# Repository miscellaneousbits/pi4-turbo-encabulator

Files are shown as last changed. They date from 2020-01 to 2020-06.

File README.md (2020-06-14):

# Raspberry Pi4 Turbo Encabulator
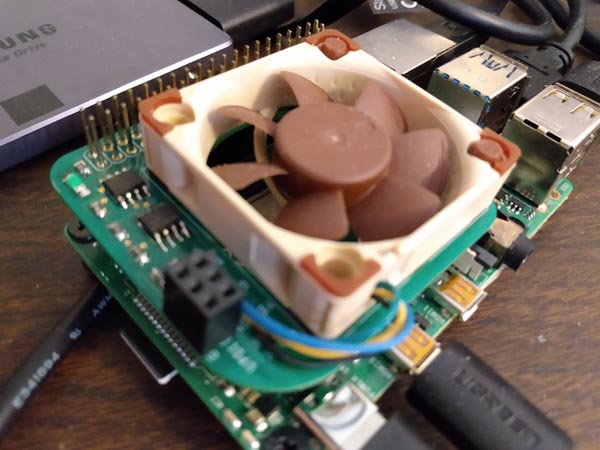
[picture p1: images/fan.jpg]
Image of Encabulator


I wanted fan speed control of a 4 wire Noctua fan with PWM, but I didn't want to dedicate one of the Pi's PWM pin for that purpose. I decided to use I2C, a shareable bus, for fan control. Ended up using a small 8 pin Atmel micro controller to support I2C and PWM to the fan. The second 8 pin package is a dual FET to handle 3.3V to 5V conversions.

## Building the Turbo Encabulator hat

You'll find everything you need in the hardware folder. Use the bill of materials file to place your parts order. Also place your board order with the fabricator. Gerber files and Exelon drill files are the standard inputs for the board fab. The design uses surface mount parts, and hand soldering the fine pitch components can be challenging.

## Programming the Atmel ATtiny212

The ATtiny212 packs an amazing amount of capabilities for an 8 bit processor in an 8 pin package (and we use all 8 pins!). I use it here to implement an I2C slave interface and a PWM generator for the fan. The microcontroller has dedicated I2C and PWM hadware blocks, so no bit banging involved... Nice! Once the board is built you can use the 3 pin UPDI header and an appropriate programmer to write its software to on-chip flash. No need to purchase a commercial UPDI programmer, look [here](https://www.jsykora.info/2019/04/avr-updi-programmer-from-attiny817-xplained-mini/) for a cheap solution using a $15 ATtiny817 Xplained Mini.

Install and use Atmel Studio 7 to build and flash the ATTiny212.asln project from folder atmel-source using your programmer. Programmer support is built in to Atmel Studio.

## Controlling the fan

Done building and programing the hat. Now to control it.

To build and install the fanmon daemon under Raspbian:

```
#install prerequites
sudo apt install libsystemd-dev
 
sudo make install

sudo cp fanmon.service /etc/systemd/system

sudo systemctl enable fanmon.service
sudo systemctl start fanmon.service
```

This daemon takes periodic temperature measurements and manages the fan to keep the SOC temperature below 70C.

Since this is for Pi 4, might as well take advantage of the new bug free I2C ports. With clock stretching properly supported on the new ports, we can take advantage of the ATtiny212's deep sleep mode to minimize fan circuit power consumption. In your /boot/config.txt file, comment out:

```
#dtparam=i2c_arm=on
```
and add
```
dtoverlay=i2c3,pins_2_3
```
And reboot

That's it! May your Pi never throttle again.

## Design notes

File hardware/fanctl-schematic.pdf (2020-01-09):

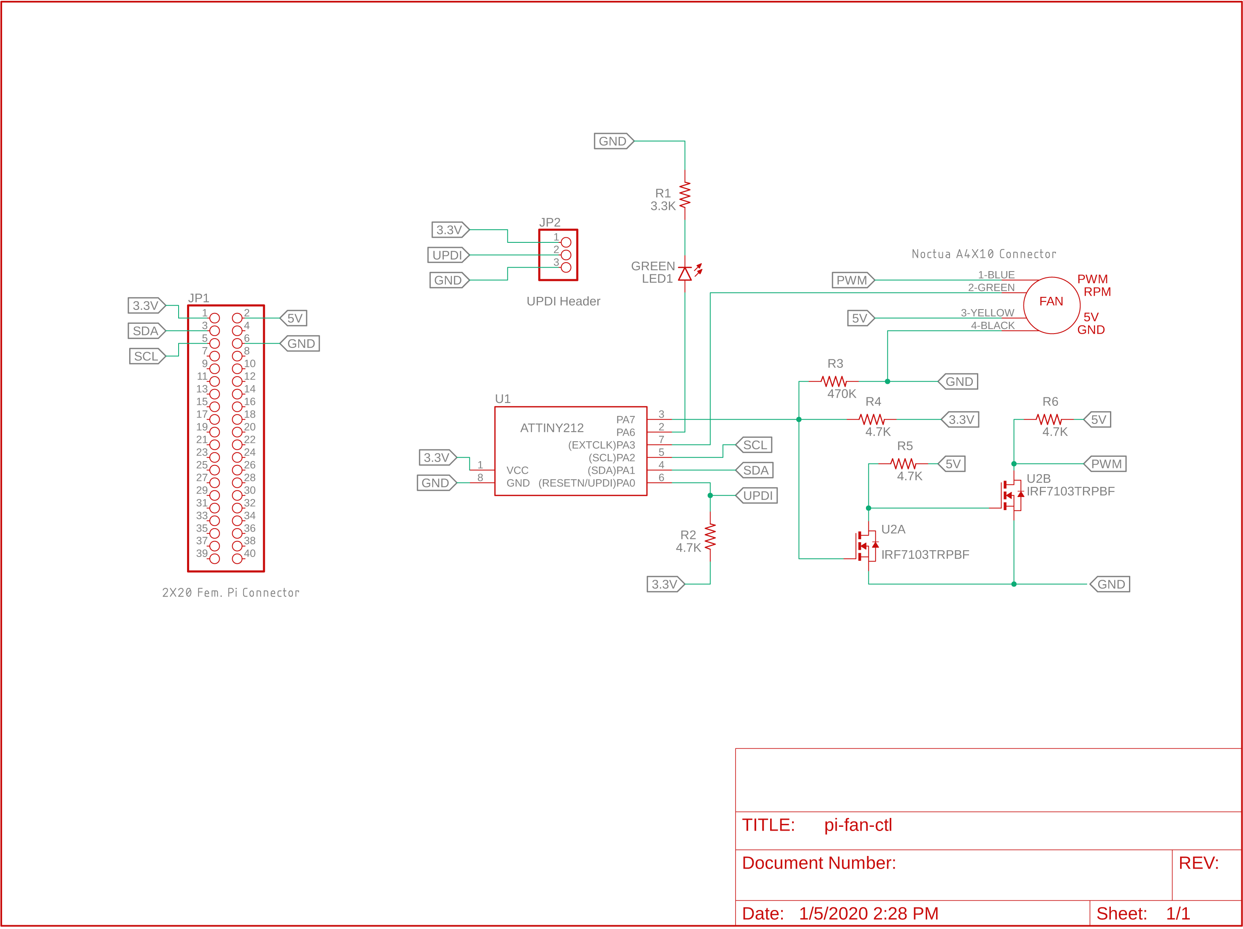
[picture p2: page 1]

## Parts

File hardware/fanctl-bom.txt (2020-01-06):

Part Value                  Device          Package                Description
F1   NOCTUA                 NOCTUA          NF-A4x10 5V PWM        FAN
JP1  Fem. Pi Connector      PINHD-2X20      2X20, Long tail        PIN HEADER
JP2  Fem. UPDI Header       PINHD-1X3       1X03                   PIN HEADER
LED1 GREEN                  CHIPLED         1206                   LED
R1   3.3K                   R-US_R0805      0805                   RESISTOR
R2   4.7K                   R-US_R0805      0805                   RESISTOR
R3   470K                   R-US_R0805      0805                   RESISTOR
R4   4.7K                   R-US_R0805      0805                   RESISTOR
R5   4.7K                   R-US_R0805      0805                   RESISTOR
R6   4.7K                   R-US_R0805      0805                   RESISTOR
U1   ATTINY212              ATTINY212       SO8                    Microcontroller
U2   IRF7103TRPBF           NMOS2SO8        SO8                    Dual MOS FET

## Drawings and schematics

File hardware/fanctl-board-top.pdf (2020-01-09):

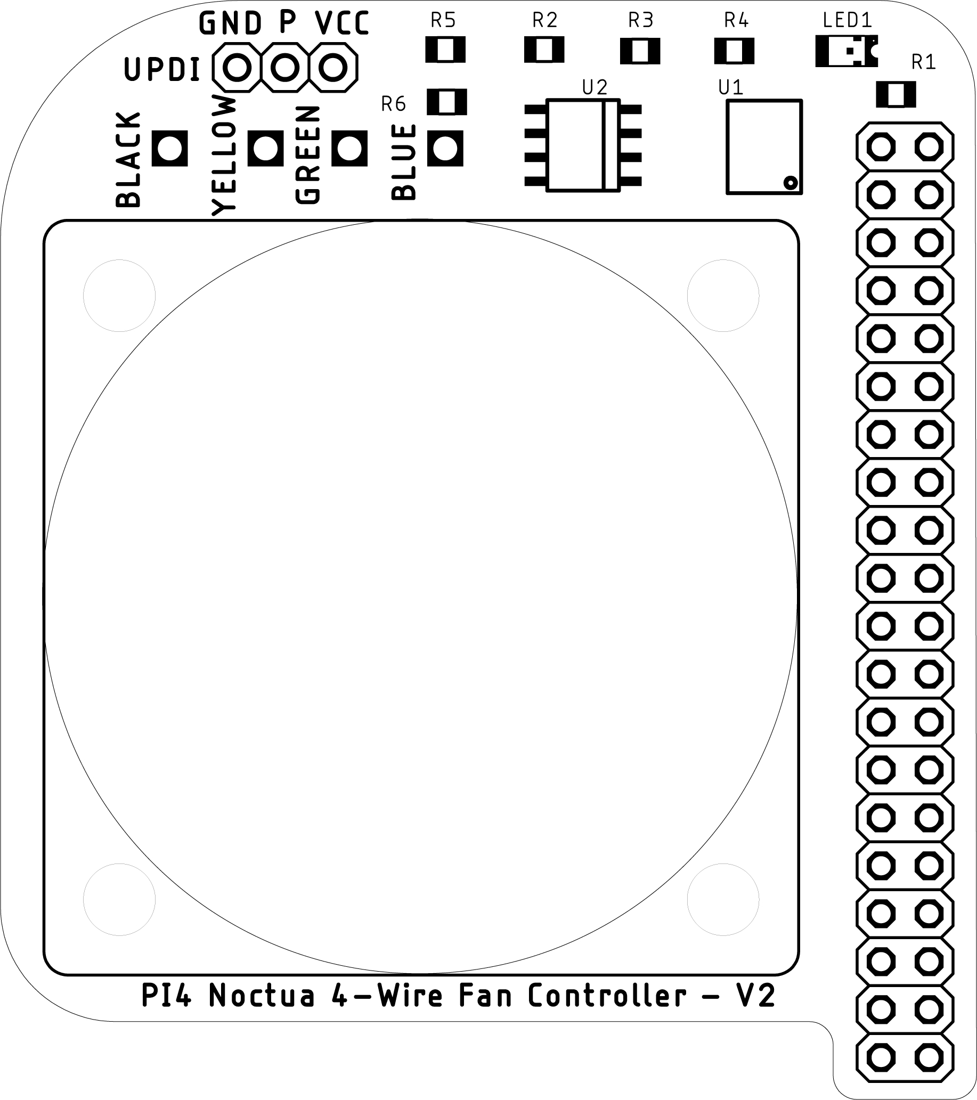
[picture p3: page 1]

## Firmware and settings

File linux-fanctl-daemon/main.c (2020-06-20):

/*
    This file is part of the pi4-turbo-encabulator.

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
    You should have received a copy of the GNU General Public License
    along with Foobar.  If not, see <https://www.gnu.org/licenses/>.
*/

#include <errno.h>
#include <signal.h>
#include <stdio.h>
#include <stdlib.h>
#include <string.h>
#include <systemd/sd-daemon.h>
#include <unistd.h>

#include "fan.h"
#include "log.h"
#include "temp.h"

static float high_temp_threshold = 78.0;  // Target max. die temp
static float low_temp_threshold = 67.0;   // Fan start temp.
static volatile uint8_t running = 1u;     // Abort (CTL-C) flag
static int logLevel = 0;                  // Log verbosity

// Catch terminal events
static void ctlc_handler(int s)
{
    running = 0;
}

// display help to stdout
static void help(char* av)
{
    printf(
        "\nUsage:\n\n"
        "%s [-v loglevel] [-l lowTemp] [-h highTemp] \n\n"
        "  -v Set log verbosity. 0 - quiet (default), 1-chatty, 2-debug\n"
        "  -l Low temperature threshold in Celcius (default - %d)\n"
        "  -m High temperature threshold in Celcius (default - %d)\n\n",
        av, (int)low_temp_threshold, (int)high_temp_threshold);
}

// Use exponential smoothing
static uint8_t Average(float p)
{
    static float sum = 0;
    sum = (sum + sum + p) / 3;
    return sum;
}

// Run once per sampling interval process
static int process_interval(void)
{
    uint32_t temp = getTemp();
    // Get the temperature and set the fan speed
    if (temp == 0)
    {
        Log(LOG_ERR, "%sError retrieving temperature\n");
        return -1;
    }
    // Calculate new fan speed in the 0-127 range
    float p;
    if (temp <= low_temp_threshold)
        p = 0;
    else if (temp >= high_temp_threshold)
        p = 127;
    else
        p = ((temp - low_temp_threshold) * 127.0) /
            (high_temp_threshold - low_temp_threshold);
    // Apply smoothing
    uint8_t ap = Average(p);
    // Set the fan speed
    fanPower(ap);
    // Conditionally log the full status
    static uint8_t lastP = 0;
    // for verbosity >= 1, log fan on/off transitions
    if (logLevel > 0)
    {
        if ((lastP && !ap) || (!lastP && ap))
            Log(LOG_INFO, "Fan o%s\n", ap ? "n" : "ff");
        lastP = ap;
    }
    // for verbosity > 1, log die temp and fan rpm at every interval
    if (logLevel > 1)
        Log(LOG_INFO, "FAN %u% TEMP %u RPM %u\n", (ap * 128) / 100, temp,
            fanRPM());
    return 0;
}

int main(int ac, char* av[])
{
    const uint32_t poll_interval = 2;

    LogInit();

    // Parse parameters
    int opt;
    while ((opt = getopt(ac, av, "v:l:m:h")) != -1)
    {
        switch (opt)
        {
        case 'v':
            logLevel = atoi(optarg);
            break;
        case 'l':
            low_temp_threshold = atoi(optarg);
            break;
        case 'm':
            high_temp_threshold = atoi(optarg);
            break;
        case 'h':
            help(av[0]);
            exit(0);
        case ':':
            Log(LOG_ERR, "option needs a value\n");
            help(av[0]);
            goto error;
        case '?':
            Log(LOG_ERR, "unknown option: %c\n", optopt);
            help(av[0]);
            goto error;
        }
    }

    // Starting
    Log(LOG_INFO, "Fan control starting, log level %d\n", logLevel);

    // Intercept sigterm
    struct sigaction sigIntHandler;
    sigIntHandler.sa_handler = ctlc_handler;
    sigemptyset(&sigIntHandler.sa_mask);
    sigIntHandler.sa_flags = 0;

    sigaction(SIGINT, &sigIntHandler, NULL);
    sigaction(SIGHUP, &sigIntHandler, NULL);
    sigaction(SIGSTOP, &sigIntHandler, NULL);
    sigaction(SIGTERM, &sigIntHandler, NULL);
    sigaction(SIGKILL, &sigIntHandler, NULL);

    // Initialize the library
    if (fanInit() < 0)
    {
        Log(LOG_ERR, "Must run as ROOT\n");
        errno = EPERM;
        goto error;
    }

    if (tempOpen() < 0)
    {
        Log(LOG_ERR, "Can't init temperature sensor\n");
        errno = EPERM;
        goto error;
    }

    // Inform systemd we've started
    sd_notify(0, "READY=1");

    // Poll forever
    for (; running;)
    {
        if (process_interval())
            goto error;
        sleep(poll_interval);
    }

    // Time to exit...
    fanClose();
    tempClose();
    Log(LOG_INFO, "Stopped\n");
    return 0;

error:
    // Exit with error.
    fanClose();
    tempClose();
    Log(LOG_ERR, "Stopped with error\n");
    sd_notifyf(0,
        "STATUS=Failed: %s\n"
        "ERRNO=%d",
        strerror(errno), errno);
    return -1;
}

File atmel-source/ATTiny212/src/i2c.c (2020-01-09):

/*
    This file is part of the pi4-turbo-encabulator.

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
    You should have received a copy of the GNU General Public License
    along with Foobar.  If not, see <https://www.gnu.org/licenses/>.
*/

#include "i2c.h"
#include "port.h"
#include "rpm.h"

// Pick an I2C slave address for the fan controller
#define I2C_SLAVE_ADDRESS 0x2c

// We are either handling data, or idle.
enum
{
    IDLE_STATE = 0,
    DATA_STATE
};

// Fan control global
// -1 : Fan PWM has been updated
// 0-127 : Nes fan speed for PWM
volatile int8_t g_fan_control = -1;

// Current state starts off idle
static uint8_t state = IDLE_STATE;

// I2C receive handler. Called by interrupt on receiving byte
static inline void i2c_recv(uint8_t b, uint8_t addr)
{
    // address byte
    if (addr)
    {
        // Since we only handle single byte messages, the address
        // is unused so we ignore it, but we to exit idle state
        state = DATA_STATE;
        return;
    }

    // data byte, reject it if idle
    if (state == IDLE_STATE)
        return;
    // Store received byte as new fan speed setting
    g_fan_control = b & 0x7f;
    // Done, drop back to idle state
    state = IDLE_STATE;
}

// I2C request handler. Called by interrupt handler when TX data
// is needed.
static inline uint8_t i2c_req(void)
{
    // Ignore if idle
    if (state == IDLE_STATE)
        return 0;
    // Send latest RPM count, and go idle
    state = IDLE_STATE;
    return g_rotations;
}

void I2C_init()
{
    // Add internal pull ups on I2C clock and data pins
    PORT_set_pull_up(SCL_PORT);
    PORT_set_pull_up(SDA_PORT);
    // Set the I2C controller slave address
    TWI0.SADDR = I2C_SLAVE_ADDRESS << 1;
    // Start the I2C controller with iterrupt enabled
    TWI0.SCTRLB = 0;
    TWI0.SCTRLA = TWI_DIEN_bm | TWI_APIEN_bm | TWI_PIEN_bm | TWI_ENABLE_bm;
}

// I2C interrupt handler
ISR(TWI0_TWIS_vect)
{
    uint8_t sstatus = TWI0.SSTATUS;
    // Data interrupt
    if (sstatus & TWI_DIF_bm)
    {
        if (TWI0.SSTATUS & TWI_DIR_bm)
            // Send
            TWI0.SDATA = i2c_req();
        else
            // Receive
            i2c_recv(TWI0.SDATA, false);
        // Acknowledge transaction
        TWI0.SCTRLB = TWI_SCMD_RESPONSE_gc;
        return;
    }
    // Address or stop interrupt
    if (sstatus & TWI_APIF_bm)
    {
        // address
        if (sstatus & TWI_AP_bm)
        {
            // Discard the address
            i2c_recv(TWI0.SDATA, true);
            // Ack the transaction
            TWI0.SCTRLB = TWI_SCMD_RESPONSE_gc;
        }
        // stop
        else
            // End the transaction
            TWI0.SCTRLB = TWI_SCMD_COMPTRANS_gc;
    }
}

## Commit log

2020-01-06 Clean BOM
2020-01-09 Show board top with parts placement

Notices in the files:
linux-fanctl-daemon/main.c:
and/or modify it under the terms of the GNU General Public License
